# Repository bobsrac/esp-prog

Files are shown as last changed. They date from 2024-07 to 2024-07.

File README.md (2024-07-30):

# esp-prog

esp32 programmer - USBC to custom DF13-7 connector

This is from the circuit on the [ESP32-C6-DevKitC-1](https://docs.espressif.com/projects/esp-dev-kits/en/latest/esp32c6/esp32-c6-devkitc-1/user_guide.html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)
board from Espressif.  It includes the USB-UART, BJT translators for reset and
boot mode, and a 3.3V LDO.

* Full kicad sources included
* Tested by flashing ESP32-C6-WROOM-1-N8 module using cargo-espflash

## images

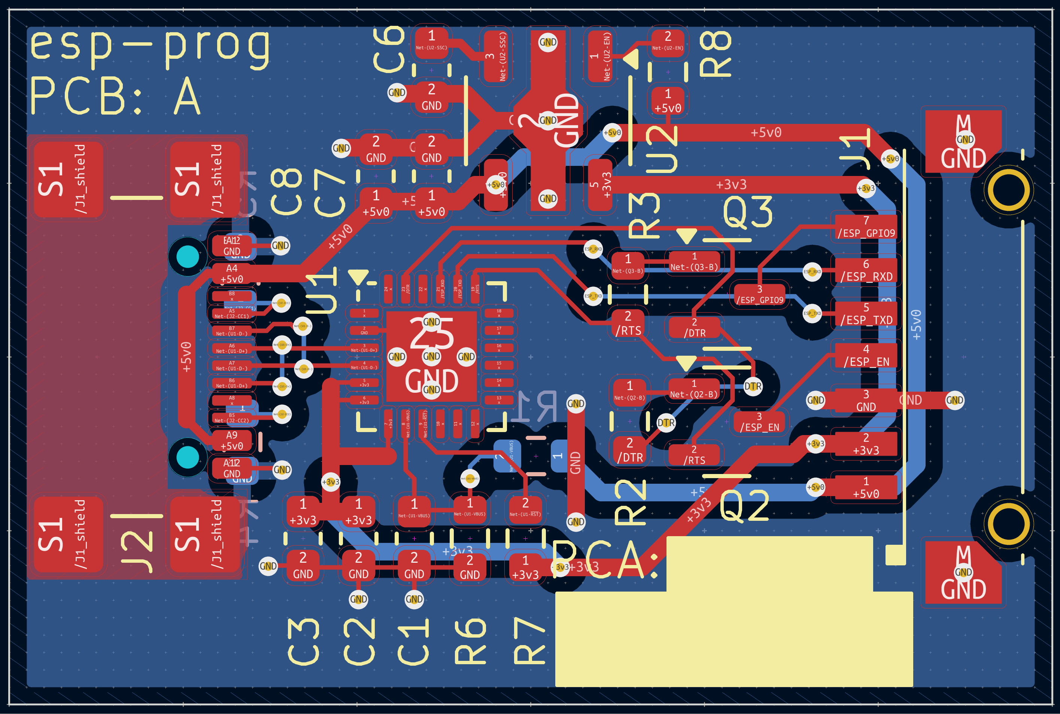
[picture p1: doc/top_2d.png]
Top 2D

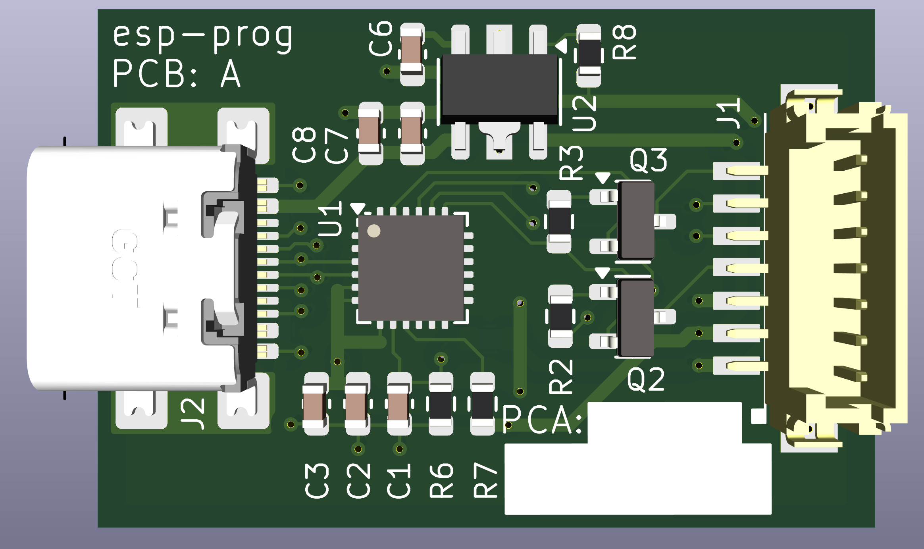
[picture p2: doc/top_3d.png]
Top 3D

Functional Instance

## PCA BOM

DigiKey buy list for the PCA (was $11.66 at time of writing) - NOTE: this
is for PCA only.  No target or PC (USB-C) cable parts included:
[http://www.digikey.com/en/mylists/list/WV3N0IXJLB](http://www.digikey.com/en/mylists/list/WV3N0IXJLB)

## PC Cable

The CP2102N is a USB 2.0 full-speed (12 Mbit/s) device, so any USB-C cable with
data lanes should work.

## Target Cable

DigiKey buy list for cable (was $7.54 at time of writing):
[http://www.digikey.com/en/mylists/list/WWA0BU113L](http://www.digikey.com/en/mylists/list/WWA0BU113L)

DF13-7S-1.25C, qty 2:
[http://www.digikey.com/en/products/detail/hirose-electric-co-ltd/DF13-7S-1-25C/241754](http://www.digikey.com/en/products/detail/hirose-electric-co-ltd/DF13-7S-1-25C/241754)

H4BBG-10104-B6, qty 10:
[http://www.digikey.com/en/products/detail/hirose-electric-co-ltd/H4BBG-10104-B6/425553](http://www.digikey.com/en/products/detail/hirose-electric-co-ltd/H4BBG-10104-B6/425553)

Route pin 1 to pin1, and pin 7 to pin 7.  With the pre-crimped wires from
Digi-Key, the cable will want to lay with both connectors facing the same
direction, with a half-twist in the middle.  With the wires all laying flat and
in parallel, one connector will be up while the other is down.

## Template for Target PCA (Board to be programmed)

See [target-template](target-template/).

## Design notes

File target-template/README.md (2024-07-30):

# esp-prog target-template

PCA design for a board with a ESP32-C6-WROOM-1, power-only USB-C connector,
3.3V LDO, programming connector for the esp-prog, and some testpoints.

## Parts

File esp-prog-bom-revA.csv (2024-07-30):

Reference | Value | Datasheet | Footprint | Qty | DNP | Manuf | Manuf PN
C1,C2,C7 | 10u | ~ | Capacitor_SMD:C_0603_1608Metric | 3 |  | Murata Electronics | GRM188Z71A106KA73D
C3 | 0.1u | ~ | Capacitor_SMD:C_0603_1608Metric | 1 |  | Yageo | CC0603KRX7R7BB104
C6 | DNP | ~ | Capacitor_SMD:C_0603_1608Metric | 1 | DNP | Murata Electronics | GRT1885C1E103JA02J
C8 | DNP | ~ | Capacitor_SMD:C_0603_1608Metric | 1 | DNP | Murata Electronics | GRM188Z71A106KA73D
J1 | ~ | https://www.hirose.com/en/product/document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 | HVAC:Hirose_DF13-7P-1.25V | 1 |  | Hirose | DF13-7P-1.25V(76)
J2 | USB4110-GF-A | https://www.mouser.com/datasheet/2/837/GCT_USB4110_Product_Drawing___20k_cycles-3455479.pdf | HVAC:USB4110-GF-A | 1 |  | GCT | USB4110-GF-A
Q2,Q3 | BC846 | https://assets.nexperia.com/documents/data-sheet/BC846_SER.pdf | Package_TO_SOT_SMD:SOT-23 | 2 |  | Nexeria USA, Inc | BC846,215
R1 | 22K1 | ~ | Resistor_SMD:R_0603_1608Metric | 1 |  | Yageo | RC0603FR-0722K1L
R2,R3,R4,R5,R7,R8 | 5K1 | ~ | Resistor_SMD:R_0603_1608Metric | 6 |  | Yageo | RC0603FR-075K1L
R6 | 47K5 | ~ | Resistor_SMD:R_0603_1608Metric | 1 |  | Yageo | RC0603FR-0747K5L
U1 | CP2102N-Axx-xQFN24 | https://www.silabs.com/documents/public/data-sheets/cp2102n-datasheet.pdf | Package_DFN_QFN:QFN-24-1EP_4x4mm_P0.5mm_EP2.6x2.6mm | 1 |  | Silicon Labs | CP2102N-A02-GQFN24R
U2 | S-13A1C33-U5T1U3 | https://www.ablic.com/en/doc/datasheet/voltage_regulator/S13A1_E.pdf | HVAC:SOT-89-5 | 1 |  | ABLIC Inc | S-13A1C33-U5T1U3

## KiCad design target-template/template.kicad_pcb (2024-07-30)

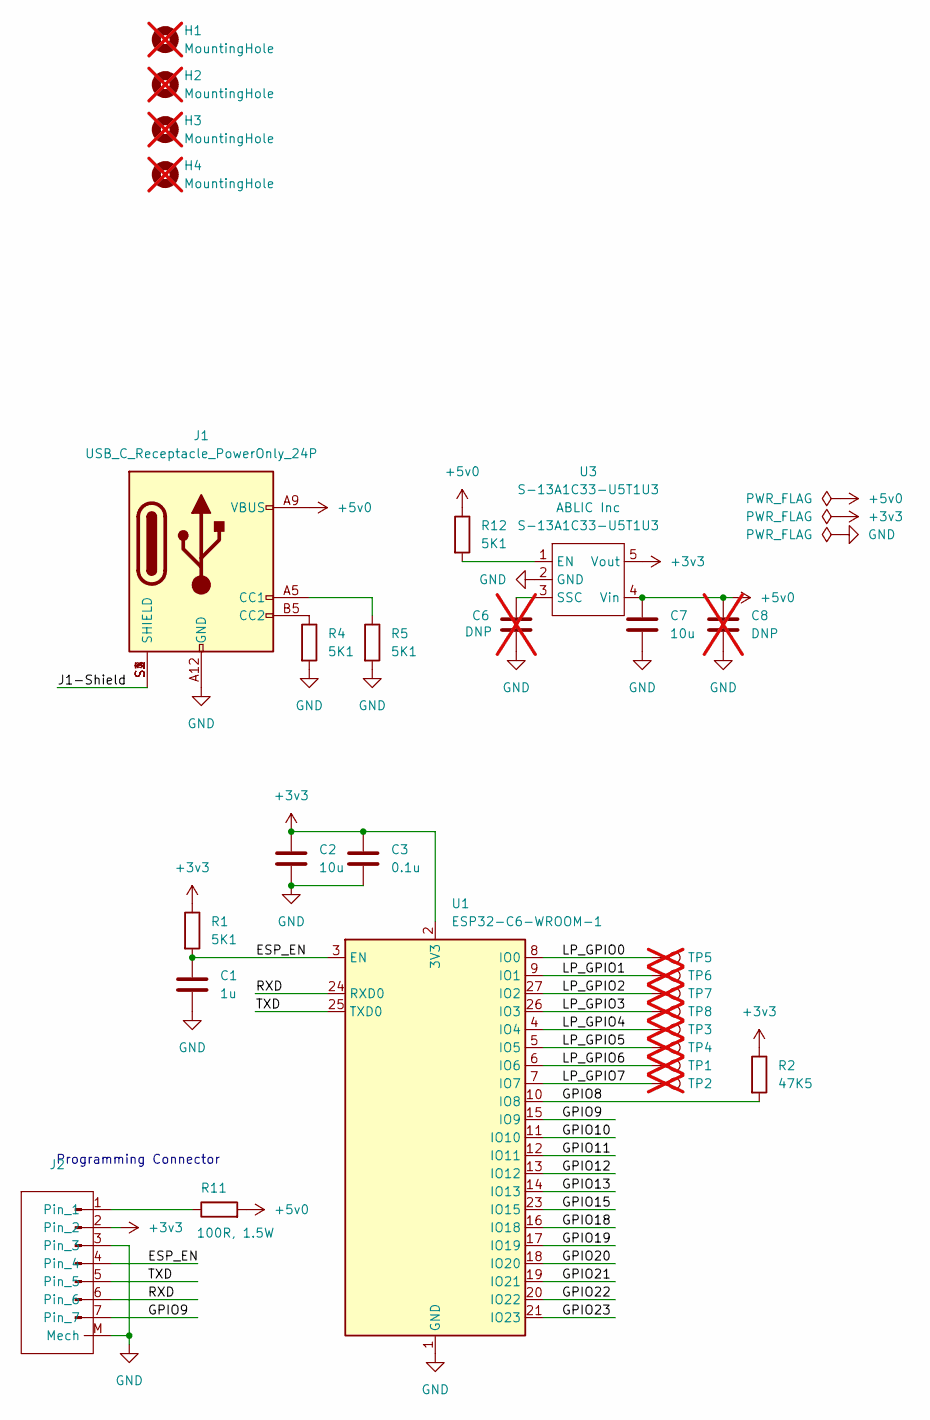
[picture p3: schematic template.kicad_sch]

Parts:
C1: 1u; C_0603_1608Metric; Manuf PN CL10B105KP8NNNC
C2, C7: 10u; C_0603_1608Metric; Manuf PN GRM188Z71A106KA73D
C3: 0.1u; C_0603_1608Metric; Manuf PN CC0603KRX7R7BB104
C6: DNP; C_0603_1608Metric; Manuf PN GRT1885C1E103JA02J; not fitted
C8: DNP; C_0603_1608Metric; Manuf PN GRM188Z71A106KA73D; not fitted
H1, H2, H3, H4: MountingHole; MountingHole_2.7mm_M2.5; not fitted
J1: USB_C_Receptacle_PowerOnly_24P; UJC-HP-G-5-SMT-TR; Manuf PN UJC-HP-G-5-SMT-TR
J2: Hirose_DF13-7P-1.25V; Manuf PN DF13-7P-1.25V(76)
R1, R4, R5, R12: 5K1; R_0603_1608Metric; Manuf PN RC0805FR-075K1L
R2: 47K5; R_0603_1608Metric; Manuf PN RC0603FR-0747K5L
R11: 100R, 1.5W; R_0612_1632Metric; Manuf PN LTR18EZPF1000
TP1, TP2, TP3, TP4, TP5, TP6, TP7, TP8: TestPoint; TestPoint_Pad_1.0x1.0mm; not fitted
U1: ESP32-C6-WROOM-1; Manuf PN ESP-32-C6-WROOM-1-N8
U3: S-13A1C33-U5T1U3; SOT-89-5; Manuf PN S-13A1C33-U5T1U3

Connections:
+3v3: C2.1, C3.1, J2.2, R1.1, R2.1, U1.2 (3V3), U3.5 (Vout)
+5v0: C7.1, C8.1, J1.A4 (VBUS), J1.A9 (VBUS), J1.B4 (VBUS), J1.B9 (VBUS), R11.2, R12.1, U3.4 (Vin)
/ESP_EN: C1.1, J2.4, R1.2, U1.3 (EN)
/GPIO8: R2.2, U1.10 (IO8)
/GPIO9: J2.7, U1.15 (IO9)
/GPIO10: U1.11 (IO10)
/GPIO11: U1.12 (IO11)
/GPIO12: U1.13 (IO12)
/GPIO13: U1.14 (IO13)
/GPIO15: U1.23 (IO15)
/GPIO18: U1.16 (IO18)
/GPIO19: U1.17 (IO19)
/GPIO20: U1.18 (IO20)
/GPIO21: U1.19 (IO21)
/GPIO22: U1.20 (IO22)
/GPIO23: U1.21 (IO23)
/J1-Shield: J1.S1 (SHIELD), J1.S2 (SHIELD), J1.S3 (SHIELD), J1.S4 (SHIELD)
/LP_GPIO0: TP5.1, U1.8 (IO0)
/LP_GPIO1: TP6.1, U1.9 (IO1)
/LP_GPIO2: TP7.1, U1.27 (IO2)
/LP_GPIO3: TP8.1, U1.26 (IO3)
/LP_GPIO4: TP3.1, U1.4 (IO4)
/LP_GPIO5: TP4.1, U1.5 (IO5)
/LP_GPIO6: TP1.1, U1.6 (IO6)
/LP_GPIO7: TP2.1, U1.7 (IO7)
/RXD: J2.6, U1.24 (RXD0)
/TXD: J2.5, U1.25 (TXD0)
GND: C1.2, C2.2, C3.2, C6.2, C7.2, C8.2, J1.A1 (GND), J1.A12 (GND), J1.B1 (GND), J1.B12 (GND), J2.3, J2.M (Mech), R4.2, R5.2, U1.1 (GND), U1.28 (GND), U1.29 (GND), U3.2 (GND)
unnamed: J1.A5 (CC1), R5.1
unnamed: J1.B5 (CC2), R4.1
unnamed: J2.1, R11.1
unnamed: R12.2, U3.1 (EN)
unnamed: C6.1, U3.3 (SSC)

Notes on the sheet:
Programming Connector

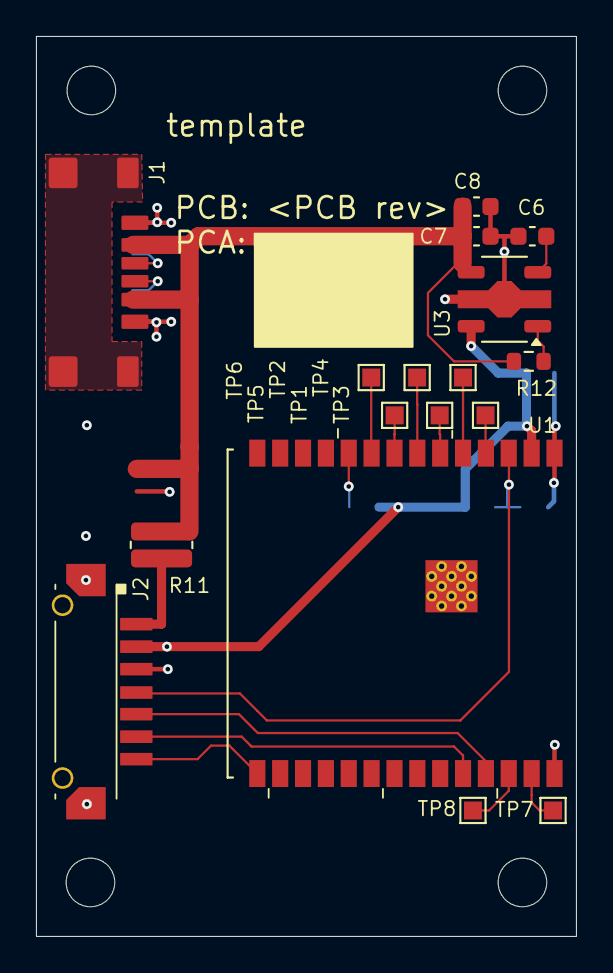
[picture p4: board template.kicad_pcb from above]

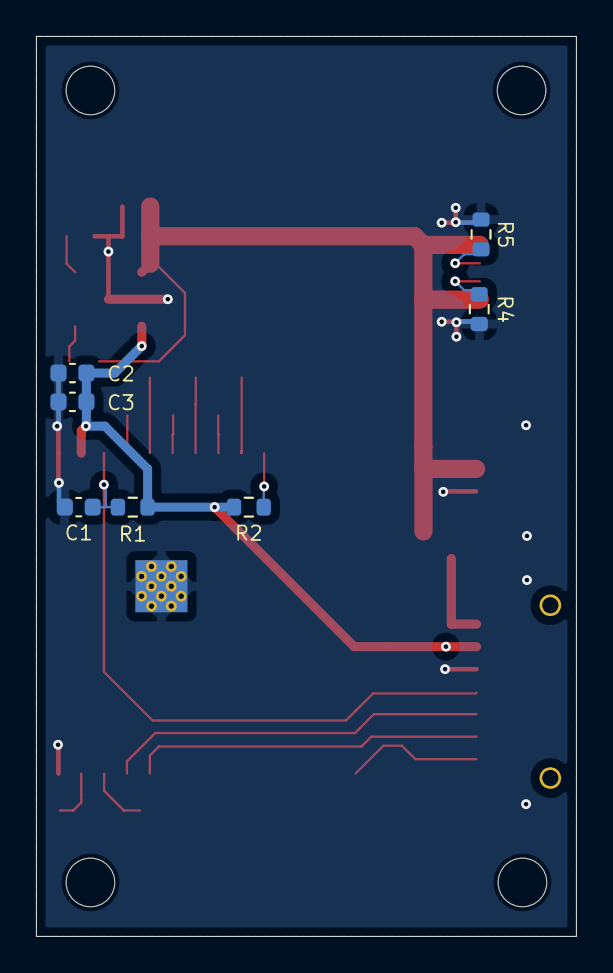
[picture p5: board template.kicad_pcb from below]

Board: 2 copper layers, 30.0 x 50.0 mm, 28 parts (7 on the bottom side), 22 nets.

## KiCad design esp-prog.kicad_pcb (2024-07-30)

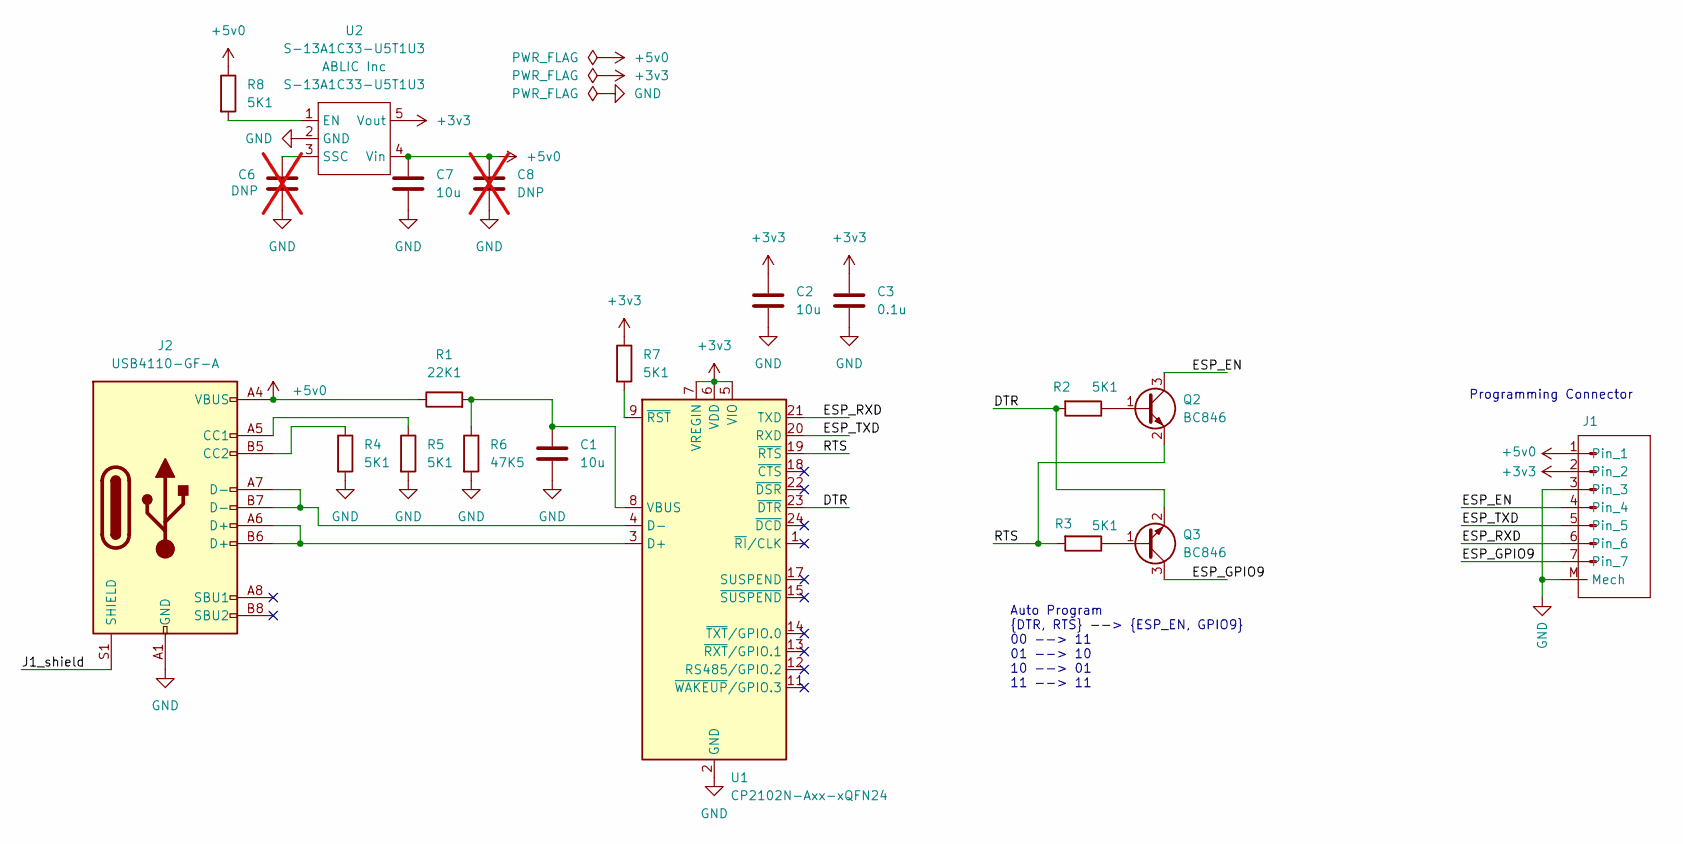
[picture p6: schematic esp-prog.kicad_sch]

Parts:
C1, C2, C7: 10u; C_0603_1608Metric; Manuf PN GRM188Z71A106KA73D
C3: 0.1u; C_0603_1608Metric; Manuf PN CC0603KRX7R7BB104
C6: DNP; C_0603_1608Metric; Manuf PN GRT1885C1E103JA02J; not fitted
C8: DNP; C_0603_1608Metric; Manuf PN GRM188Z71A106KA73D; not fitted
J1: Hirose_DF13-7P-1.25V; Manuf PN DF13-7P-1.25V(76)
J2: USB4110-GF-A; Manuf PN USB4110-GF-A
Q2, Q3: BC846; SOT-23; Manuf PN BC846,215
R1: 22K1; R_0603_1608Metric; Manuf PN RC0603FR-0722K1L
R2, R3, R4, R5, R7, R8: 5K1; R_0603_1608Metric; Manuf PN RC0603FR-075K1L
R6: 47K5; R_0603_1608Metric; Manuf PN RC0603FR-0747K5L
U1: CP2102N-Axx-xQFN24; QFN-24-1EP_4x4mm_P0.5mm_EP2.6x2.6mm; Manuf PN CP2102N-A02-GQFN24R
U2: S-13A1C33-U5T1U3; SOT-89-5; Manuf PN S-13A1C33-U5T1U3

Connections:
+3v3: C2.1, C3.1, J1.2, R7.1, U1.5 (VIO), U1.6 (VDD), U1.7 (VREGIN), U2.5 (Vout)
+5v0: C7.1, C8.1, J1.1, J2.A4 (VBUS), J2.A9 (VBUS), J2.B4 (VBUS), J2.B9 (VBUS), R1.1, R8.1, U2.4 (Vin)
/DTR: Q3.2 (E), R2.2, U1.23 (~DTR)
/ESP_EN: J1.4, Q2.3 (C)
/ESP_GPIO9: J1.7, Q3.3 (C)
/ESP_RXD: J1.6, U1.21 (TXD)
/ESP_TXD: J1.5, U1.20 (RXD)
/J1_shield: J2.S1 (SHIELD)
/RTS: Q2.2 (E), R3.2, U1.19 (~RTS)
GND: C1.2, C2.2, C3.2, C6.2, C7.2, C8.2, J1.3, J1.M (Mech), J2.A1 (GND), J2.A12 (GND), J2.B1 (GND), J2.B12 (GND), R4.2, R5.2, R6.2, U1.2 (GND), U1.25 (GND), U2.2 (GND)
unnamed: J2.A5 (CC1), R5.1
unnamed: J2.B5 (CC2), R4.1
unnamed: Q2.1 (B), R2.1
unnamed: Q3.1 (B), R3.1
unnamed: J2.A6 (D+), J2.B6 (D+), U1.3 (D+)
unnamed: J2.A7 (D-), J2.B7 (D-), U1.4 (D-)
unnamed: C1.1, R1.2, R6.1, U1.8 (VBUS)
unnamed: R7.2, U1.9 (~RST)
unnamed: R8.2, U2.1 (EN)
unnamed: C6.1, U2.3 (SSC)

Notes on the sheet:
Auto Program {DTR, RTS} --> {ESP_EN, GPIO9} 00 --> 11 01 --> 10 10 --> 01 11 --> 11
Programming Connector

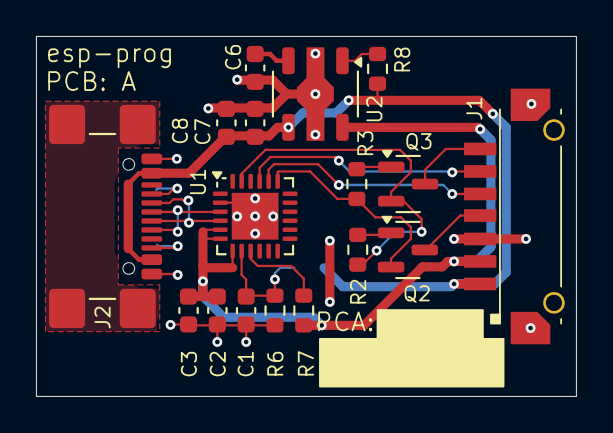
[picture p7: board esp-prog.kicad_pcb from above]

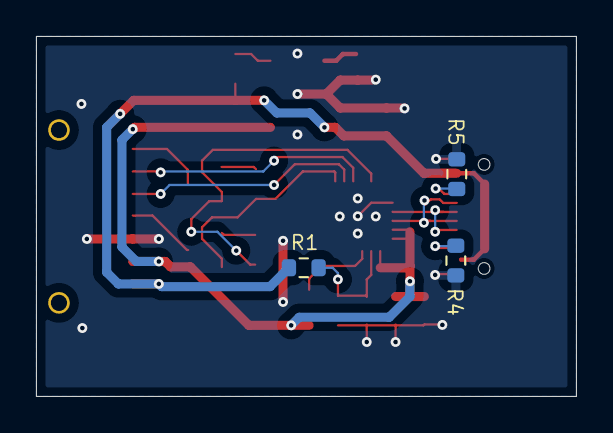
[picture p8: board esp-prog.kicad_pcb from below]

Board: 2 copper layers, 30.0 x 20.0 mm, 20 parts (3 on the bottom side), 19 nets.

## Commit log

2024-07-30 revA as-built
    [esp-prog-B_Cu.gbr, esp-prog-B_Mask.gbr, esp-prog-B_Paste.gbr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]
2024-07-30 added template for a target PCA
    [template.kicad_pcb, template.kicad_sch]
